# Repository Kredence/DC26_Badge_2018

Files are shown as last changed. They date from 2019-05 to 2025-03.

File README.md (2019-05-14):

Thanks to inspiration from everyone at DC25!

Status:
Currently the rev1a board had a ~6 bad traces and had to be fixed.

Board rev1b has all of the traces fixed but I goobered up the pin layout for the Feather 328P.
  1. A couple bodge wires gets it up and running.
  2. I had to stop and laugh. I picked a feather because it has an onboard lipo charger.
     For some reason I had the bright idea to point the USB port at the battery.
     Basically, you can either plug in a battery or USB cable but not booth. Derp.
     Adding a $1.50 usb micro breakout board to the extra space on the feather gave me charging back!
Board rev1c will be finished after the Con. I'll post it up on PCBway if anyone wants to buy and build them.
I'll have the BOM and code here.

Update (end of 2018): Board Rev1C was completed and will be available as a kit shortly.

Update early 2019: I was seriously delayed in getting the board construction tutorial created along with releasing the board coding. I had intended to do a full re-write on the code. I've decided to simply post what was running at the conference instead of delaying the release. :-)

"ThursdayNight" is the code that ran on the badge during the conference. Some of you heard the story but I had a hard drive failure, while working on code, on our way to DEFCON. ThursdayNight was a rushed rebuild. It works well but some of the special effects I had written are gone. I hope to sit down and rewrite it again soon.

You'll need the DC26_Illuminati.cpp and DC26_Illuminati.h files allowing with installing the Adafruit_GFX.h library.

Thanks!
Kredence

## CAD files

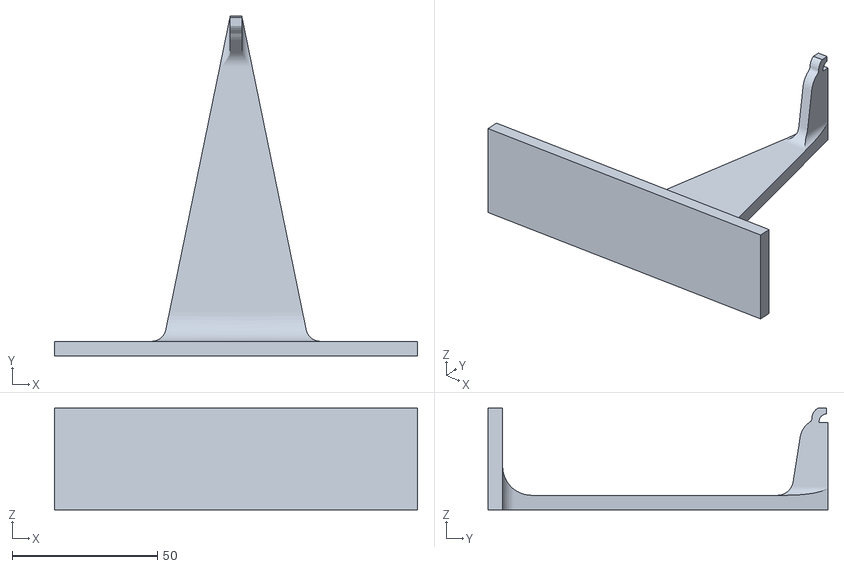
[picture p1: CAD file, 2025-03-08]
DC26 Stand v3.stl
125.0 x 117.0 x 35.0

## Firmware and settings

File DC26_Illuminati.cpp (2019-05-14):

/*
The original authors and framework of the IS31FL3731 coding was done by Adafruit.
The original coding is heavily modified, non-existent, or has been expanded.
You'll want to install the Adafruit GFX library along with the DC26_Illuminati.cpp and DC26_Illuminati.h

The DEFCON 26 Illuminati Badge schematics, PCB layout, and coding was done by Kredence.
A substantial portion of the assembly and PR/advertising was done by Ajax.
*/

#include <Arduino.h>
#include <Adafruit_GFX.h>
#include <Wire.h>
#include <DC26_Illuminati.h>

#ifndef _swap_int16_t
#define _swap_int16_t(a, b) { int16_t t = a; a = b; b = t; }
#endif


/* Constructor */
DC26_Illuminati::DC26_Illuminati(uint8_t x, uint8_t y) : Adafruit_GFX(x, y) {
}



boolean DC26_Illuminati::begin(uint8_t addr) {
  Wire.begin();

  _i2caddr = addr;
  _frame = 0;

  // shutdown
  writeRegister8(ISSI_BANK_FUNCTIONREG, ISSI_REG_SHUTDOWN, 0x00);

  delay(10);

  // out of shutdown
  writeRegister8(ISSI_BANK_FUNCTIONREG, ISSI_REG_SHUTDOWN, 0x01);

  // picture mode
  writeRegister8(ISSI_BANK_FUNCTIONREG, ISSI_REG_CONFIG, ISSI_REG_CONFIG_PICTUREMODE);

  displayFrame(_frame);

  // all LEDs on & 0 PWM
  clear(); // set each led to 0 PWM

  for (uint8_t f=0; f<8; f++) {  
    for (uint8_t i=0; i<=0x11; i++)
      writeRegister8(f, i, 0xff);     // each 8 LEDs on
  }

  audioSync(false);

  return true;
}

void DC26_Illuminati::clear(void) {
  // all LEDs on & 0 PWM

  selectBank(_frame);

  for (uint8_t i=0; i<6; i++) {
    Wire.beginTransmission(_i2caddr);
    Wire.write((byte) 0x24+i*24);
    // write 24 bytes at once
    for (uint8_t j=0; j<24; j++) {
      Wire.write((byte) 0);
    }
    Wire.endTransmission();
  }
}

void DC26_Illuminati::setLEDPWM(uint8_t lednum, uint8_t pwm, uint8_t bank) {
	uint8_t led = translateLED(lednum);
  //if (lednum >= 144) return;
  writeRegister8(bank, 0x24+led, pwm);
}

//void DC26_Illuminati::setLEDPWM(uint8_t lednum, uint8_t pwm, uint8_t bank) {
//  if (lednum >= 144) return;
//  writeRegister8(bank, 0x24+lednum, pwm);
//}


void DC26_Illuminati::drawPixel(int16_t x, int16_t y, uint16_t color) {
 // check rotation, move pixel around if necessary
  switch (getRotation()) {
  case 1:
    _swap_int16_t(x, y);
    x = 16 - x - 1;
    break;
  case 2:
    x = 16 - x - 1;
    y = 9 - y - 1;
    break;
  case 3:
    _swap_int16_t(x, y);
    y = 9 - y - 1;
    break;
  }

  if ((x < 0) || (x >= 16)) return;
  if ((y < 0) || (y >= 9)) return;
  if (color > 255) color = 255; // PWM 8bit max

  setLEDPWM(x + y*16, color, _frame);
  return;
}

//This was used to make the LED ordering a lot easier to code
//The LED layout was a bit random due to the multiplexing of the IS31FL chip
uint8_t  DC26_Illuminati::translateLED(uint8_t call) {
	uint8_t translated;
	
	switch(call){
		case 1: translated = 0;
		break;
		case 2: translated = 16;
		break;
		case 3: translated = 32;
		break;
		case 4: translated = 48;
		break;
		case 5: translated = 64;
		break;
		case 6: translated = 80;
		break;
		case 7: translated = 96;
		break;
		case 8: translated = 112;
		break;
		case 9: translated = 128;
		break;
		case 10: translated = 1;
		break;
		case 11: translated = 17;
		break;
		case 12: translated = 33;
		break;
		case 13: translated = 49;
		break;
		case 14: translated = 65;
		break;
		case 15: translated = 81;
		break;
		case 16: translated = 97;
		break;
		case 17: translated = 113;
		break;
		case 18: translated = 129;
		break;
		case 19: translated = 2;
		break;
		case 20: translated = 18;
		break;
		case 21: translated = 34;
		break;
		case 22: translated = 50;
		break;
		case 23: translated = 66;
		break;
		case 24: translated = 82;
		break;
		case 25: translated = 98;
		break;
		case 26: translated = 114;
		break;
		case 27: translated = 130;
		break;
		case 28: translated = 3;
		break;
		case 29: translated = 19;
		break;
		case 30: translated = 35;
		break;
		case 31: translated = 51;
		break;
		case 32: translated = 67;
		break;
		case 33: translated = 83;
		break;
		case 34: translated = 99;
		break;
		case 35: translated = 115;
		break;
		case 36: translated = 131;
		break;
		case 37: translated = 20;
		break;
		case 38: translated = 4;
		break;
		case 39: translated = 36;
		break;
		case 40: translated = 52;
		break;
		case 41: translated = 68;
		break;
		case 42: translated = 84;
		break;
		case 43: translated = 100;
		break;
		case 44: translated = 116;
		break;
		case 45: translated = 132;
		break;
		case 46: translated = 21;
		break;
		case 47: translated = 5;
		break;
		case 48: translated = 37;
		break;
		case 49: translated = 53;
		break;
		case 50: translated = 69;
		break;
		case 51: translated = 85;
		break;
		case 52: translated = 101;
		break;
		case 53: translated = 117;
		break;
		case 54: translated = 133;
		break;
		case 55: translated = 22;
		break;
		case 56: translated = 6;
		break;
		case 57: translated = 38;
		break;
		case 58: translated = 54;
		break;
		case 59: translated = 70;
		break;
		case 60: translated = 86;
		break;
		case 61: translated = 102;
		break;
		case 62: translated = 118;
		break;
		case 63: translated = 134;
		break;
		case 64: translated = 7;
		break;
		case 65: translated = 23;
		break;
		case 66: translated = 39;
		break;
		case 67: translated = 55;
		break;
		case 68: translated = 71;
		break;
		case 69: translated = 87;
		break;
		case 70: translated = 103;
		break;
		case 71: translated = 119;
		break;
		case 72: translated = 135;
		break;
		case 73: translated = 8;
		break;
		case 74: translated = 24;
		break;
		case 75: translated = 40;
		break;
		case 76: translated = 56;
		break;
		case 77: translated = 72;
		break;
		case 78: translated = 88;
		break;
		case 79: translated = 9;
		break;
		case 80: translated = 25;
		break;
		case 81: translated = 41;
		break;
		case 82: translated = 57;
		break;
		case 83: translated = 73;
		break;
		case 84: translated = 89;
		break;
		case 85: translated = 10;
		break;
		case 86: translated = 26;
		break;
		case 87: translated = 42;
		break;
		case 88: translated = 58;
		break;
		case 89: translated = 74;
		break;
		case 90: translated = 90;
		break;
		case 91: translated = 11;
		break;
		case 92: translated = 27;
	}
  return translated;
}

void DC26_Illuminati::setFrame(uint8_t f) {
  _frame = f;
}

void DC26_Illuminati::displayFrame(uint8_t f) {
  if (f > 7) f = 0;
  writeRegister8(ISSI_BANK_FUNCTIONREG, ISSI_REG_PICTUREFRAME, f);
}


void DC26_Illuminati::selectBank(uint8_t b) {
 Wire.beginTransmission(_i2caddr);
 Wire.write((byte)ISSI_COMMANDREGISTER);
 Wire.write(b);
 Wire.endTransmission();
}

void DC26_Illuminati::audioSync(boolean sync) {
  if (sync) {
    writeRegister8(ISSI_BANK_FUNCTIONREG, ISSI_REG_AUDIOSYNC, 0x1);
  } else {
    writeRegister8(ISSI_BANK_FUNCTIONREG, ISSI_REG_AUDIOSYNC, 0x0);
  }
}
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
